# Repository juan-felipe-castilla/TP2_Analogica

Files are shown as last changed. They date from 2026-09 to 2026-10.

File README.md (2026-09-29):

# Laboratorio 2: Amplificador BJT Multietapa con Espejo de Corriente NMOS

Repositorio del **Laboratorio 2** para la asignatura de Electrónica. El objetivo de este proyecto es diseñar, simular, implementar en PCB y caracterizar experimentalmente un amplificador en cascada basado en transistores BJT.

---

## 👥 Integrantes (Grupo N°)
- **[Castilla Juan Felipe]** 
- **[Agustin Eduardo Dalmazzo]**
- **[Julian Lopez Bernal]** 

---

## 🎯 Especificaciones de Diseño

| Parámetro | Valor Requerido |
| :--- | :--- |
| **Ganancia de Tensión de Transf. ($G_T$)** | $> 75$ |
| **Impedancia de Entrada ($Z_{in}$)** | $> 350\text{ k}\Omega$ |
| **Impedancia de Salida ($Z_o$)** | $8\Omega \pm 5\%$ |

---

## 🛠️ Estructura del Repositorio

```text
.
├── docs/                   # Guías, hojas de datos (datasheets) e informe final
│   └── Informe_Laboratorio_2.pdf
├── design/                 # Cálculos teóricos, hojas de cálculo o notebooks
├── simulation/             # Archivos de simulación (SPICE / LTspice / Altium)
│   ├── bias_point/         # Análisis del punto de operación (OP)
│   ├── ac_analysis/        # Respuestas en frecuencia (AC)
│   └── transient/          # Análisis temporal, ruido y THD (TRAN / NOISE / FFT)
├── pcb/                    # Archivos de diseño de circuito impreso (KiCad / Altium)
│   ├── schematics/
│   ├── layout/
│   └── gerbers/
└── README.md

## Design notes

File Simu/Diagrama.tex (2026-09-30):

\documentclass[border=5mm]{standalone}
\usepackage[siunitx, american]{circuitikz}

\begin{document}
\begin{circuitikz}[scale=0.85, transform shape, line width=0.6pt]
    
    % ---------------------------------------------------
    % ETAPA 1: Entrada y Par Darlington (Q1, Q2)
    % ---------------------------------------------------
    % Fuente de entrada y NodoInput
    \draw (0,0) node[ground]{} 
          to[sV, l=$V_1$] (0,4)
          to[short, -*] (1.5,4) node[above]{NodoInput}
          to[short] (3,4) node[above]{B1};
          
    % Resistencia de base Q1
    \draw (3,4) to[R, l=$R_{BD}$] (3,0) node[ground]{};
    
    % Transistor Q1 (NPN)
    \draw (3,4) to[R, l=$h_{ie1}$, i=$i_{b1}$] (6,4) node[above right]{E1};
    \draw (6,7) node[ground, rotate=180]{} node[right]{C1} 
          to[cI, l=$\beta i_{b1}$] (6,4); 
    
    % Transistor Q2 (NPN)
    \draw (6,4) to[short] (8,4) node[above]{B2};
    \draw (8,4) to[R, l=$h_{ie2}$, i=$i_{b2}$] (11,4) node[above right]{E2};
    \draw (11,7) node[ground, rotate=180]{} node[right]{C2} 
          to[cI, l=$\beta i_{b2}$] (11,4); 
    
    % Resistencia de emisor Q2
    \draw (11,4) to[R, l=$R_{ED}$] (11,0) node[ground]{};

    % ---------------------------------------------------
    % ETAPA 2: Emisor Común (Q3)
    % ---------------------------------------------------
    % Resistencias de polarización separadas (R1E y R2E)
    \draw (11,4) to[short] (12.5,4);
    \draw (12.5,4) to[R, l=$R_{1E}$] (12.5,0) node[ground]{};
    \draw (12.5,4) to[short] (14,4);
    \draw (14,4) to[R, l=$R_{2E}$] (14,0) node[ground]{};
    
    % Transistor Q3 (NPN)
    \draw (14,4) to[short] (15.5,4) node[above]{B3};
    \draw (15.5,4) to[R, l=$h_{ie3}$, i=$i_{b3}$] (15.5,0) node[below right]{E3} node[ground]{};
    \draw (18,4) node[above]{C3} 
          to[cI, l=$\beta i_{b3}$] (18,0) node[below right]{E3} node[ground]{};
          
    % Resistencia de colector de Q3
    \draw (18,4) to[short] (19.5,4) 
          to[R, l=$R_{CE}$] (19.5,0) node[ground]{};

    % ---------------------------------------------------
    % ETAPA 3: Par Sziklai y Carga (Q4, Q5, Salida)
    % ---------------------------------------------------
    % Resistencias de polarización separadas (R1S y R2S)
    \draw (19.5,4) to[short] (21,4);
    \draw (21,4) to[R, l=$R_{1S}$] (21,0) node[ground]{};
    \draw (21,4) to[short] (22.5,4);
    \draw (22.5,4) to[R, l=$R_{2S}$] (22.5,0) node[ground]{};
    
    % Transistor Q4 (NPN)
    \draw (22.5,4) to[short] (24,4) node[above]{B4};
    \draw (24,4) to[R, l=$h_{ie4}$, i=$i_{b4}$] (27,4) node[below right]{E4};
    \draw (27,7) node[left]{C4} 
          to[cI, l=$\beta i_{b4}$] (27,4);
    
    % Transistor Q5 (PNP)
    \draw (27,7) node[above left]{B5} 
          to[R, l=$h_{ie5}$, i<=$i_{b5}$] (30,7) node[above right]{E5} node[ground, rotate=180]{};
    \draw (30,7) to[cI, l=$\beta i_{b5}$] (30,4) node[below]{C5};
    \draw (30,4) to[short] (27,4); 
    
    % NodoOut y resistencia de emisor Sziklai
    \draw (27,4) to[short, -*] (29,4) node[above]{NodoOut};
    \draw (29,4) to[R, l=$R_{ES}$] (29,0) node[ground]{};
    
    % Red de Carga final (RO y RL en serie)
    \draw (29,4) to[short] (31,4) 
          to[R, l=$R_O$] (31,2) 
          to[R, l=$R_L$] (31,0) node[ground]{};

\end{circuitikz}
\end{document}

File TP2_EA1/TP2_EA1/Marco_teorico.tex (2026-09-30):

\section{Marco Teórico}

\subsection{Amplificación en Circuitos con BJT}

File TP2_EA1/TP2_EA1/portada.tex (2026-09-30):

\begin{titlepage}

\thispagestyle{empty}

% Portada Custom, ver /maketitle: https://www.overleaf.com/learn/latex/How_to_Write_a_Thesis_in_LaTeX_(Part_5)%3A_Customising_Your_Title_Page_and_Abstract

\begin{tikzpicture}[remember picture,overlay]
    \node[opacity=0.2,anchor=center] at (current page.center) 
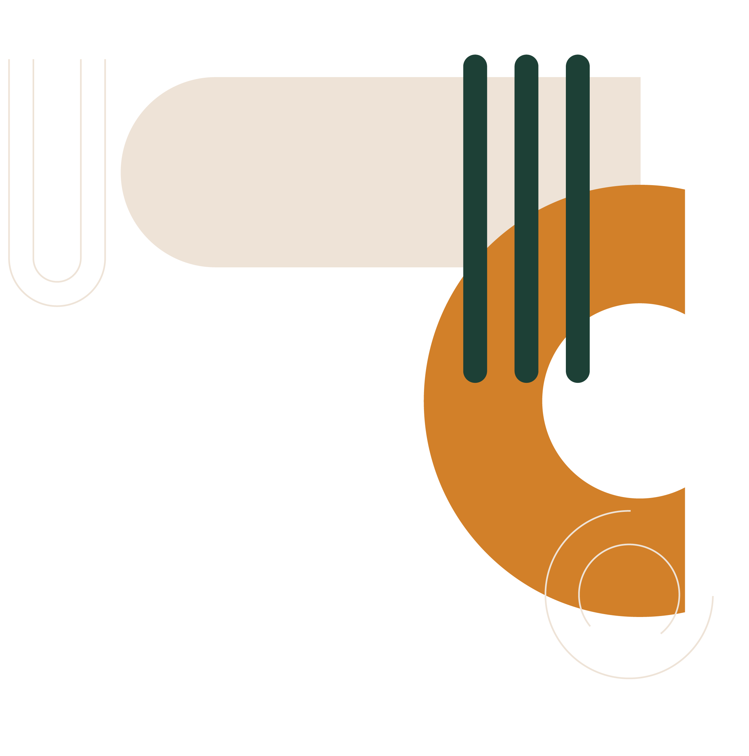
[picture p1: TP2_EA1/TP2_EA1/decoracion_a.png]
        {};
\end{tikzpicture}

\begin{center}
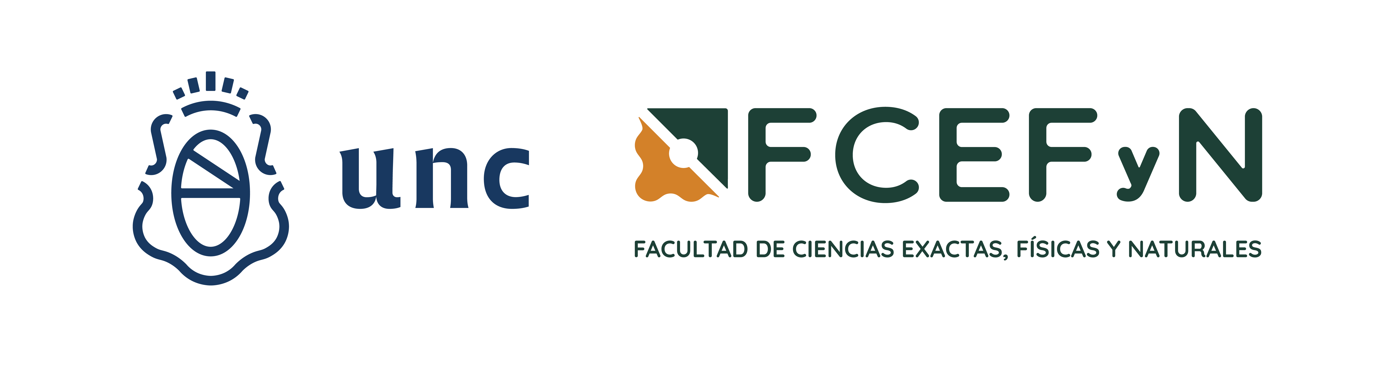
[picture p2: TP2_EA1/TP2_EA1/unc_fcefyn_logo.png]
    
    \\[0.5cm]
    \LARGE Universidad Nacional de Córdoba\\[0.5cm] 
    \large Facultad de Ciencias Exactas, Físicas y Naturales \\[0.5cm] 
    \large Materia
    \\[0.2cm]
    \large Trabajo Práctico N° 2
    \\[0.2cm]
    \vspace{60pt}
    \begin{table}[!h]
    \centering
    \begin{tabular}{ll}
    \multicolumn{1}{c}{Nombre} & \multicolumn{1}{c}{DNI} \\
    Castilla, Juan Felipe & 45.886.652 \\
    Dalmazzo, Agustín Eduardo & 46.541.615 \\
    López Bernal, Julián & 45.107.175
    \end{tabular}
    \end{table}
    \vspace{20pt}
    \begin{table}[!h]
    \centering
    \begin{tabular}{ll}
    \multicolumn{1}{c}{Docentes} & Prof. Dadam, Federico Tomás \\
     & Prof. Gallardo, Fernando José \\
     & Prof. Petrashin, Pablo Antonio \\
    \end{tabular}
    \end{table}
    \vfill
    Córdoba, República Argentina\\
    \today
\end{center}

\end{titlepage}

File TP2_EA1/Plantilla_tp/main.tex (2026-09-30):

\documentclass{article}
\usepackage[utf8]{inputenc}
\usepackage{graphicx}
\usepackage[spanish,es-tabla]{babel}
\usepackage{amsmath}
\usepackage[a4paper,margin=1in]{geometry}
\usepackage{subcaption}
\usepackage{amssymb}
\usepackage[hidelinks]{hyperref}
\usepackage{mathtools}
\usepackage[table,xcdraw]{xcolor}
\usepackage{biblatex}
\usepackage{enumitem}
\usepackage{csquotes}
\usepackage{circuitikz}
\usepackage{siunitx}

%Formateo etiquetas
\hypersetup{
    colorlinks=true,
    linkcolor=blue,    
    citecolor=blue,
    urlcolor=blue,
    filecolor=blue
}

\addbibresource{bibliografia.bib} %archivo de bibliografia

\begin{document}

%Configuro referencias automáticas
\renewcommand{\figureautorefname}{Fig.}
\renewcommand{\tableautorefname}{Tab.}
\renewcommand{\equationautorefname}{Ec.}

\input{titlepage}
\newpage
\vspace*{\fill}
\begin{center}
    (Página intencionalmente blanca) % Dejar para escribir los comentarios de corrección sobre esta página
\end{center}

\newpage

\tableofcontents
\newpage
\listoffigures
\newpage
\listoftables

\newpage

\input{seccion1}\label{section:one}
\newpage
\input{seccion2}
\newpage
\printbibliography
\end{document}

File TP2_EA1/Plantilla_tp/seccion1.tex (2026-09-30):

\section{Introducción}

Este documento contiene algunos elementos típicos usados en informes técnico o de laboratorio. Hay muchos recursos para aprender \LaTeX como:

\begin{itemize}
    \item \href{https://www.overleaf.com/learn}{Tutoriales de Overleaf}
    \item \href{https://latexguide.org/}{LaTeX Beginner's Guide}
    \item \href{https://tobi.oetiker.ch/lshort/lshort.pdf}{The Not So Short Introduction to \LaTeX}
    \item \href{https://www.latex-project.org/help/books/tlc3-digital-chapter-samples.pdf}{The \LaTeX Companion}
\end{itemize}

\subsection{Estilos de texto y listas}

Esto es un texto de ejemplo. Para generar párrafos en latex se puede escribir normalmente en un archivo \texttt{.tex}. Notar que en el editor un mismo párrafo aparece en una única línea de ``código".

Se puede modificar el estilo de texto para hacer \textit{partes en itálica} y \textbf{partes en negrita}, además se pueden incluir \texttt{palabras en fuente monoespaciada} o \underline{texto subrayado}. Además se pueden insertar listados:

\begin{itemize}
    \item Item principal
    \begin{itemize}
        \item Subitem 1
        \item Subitem 2
    \end{itemize}
    \item Otro item principal
\end{itemize}

Enumeraciones de items:

\begin{enumerate}
    \item Primer Item
    \begin{enumerate}
        \item Subitem enumerado
        \item Otro subitem enumerado
    \end{enumerate}
    \item Segundo item
\end{enumerate}

Con otro tipo de simbolos:

\begin{itemize}[label=$\Rightarrow$]
    \item Item 
    \item Otro item
        \begin{itemize}[label=$\blacktriangleright$]
            \item Un subitem
        \end{itemize}
\end{itemize}

También se pueden crear enumeraciones legales:

\begin{enumerate}[label=\arabic*.]
    \item Nivel 1, estilo legal, separado por puntos
    \begin{enumerate}[label=\theenumi\arabic*.]
        \item Nivel 2
        \begin{enumerate}[label=\theenumii\arabic*.]
            \item Nivel 3
        \end{enumerate}
    \end{enumerate}
    \item Regreso al Nivel 1
\end{enumerate}

O enumeraciones arbitrarias:

\begin{enumerate}[label=\arabic*.]
    \item Primer nivel (Número)
    \begin{enumerate}[label=\theenumi\alph*.]
        \item Segundo nivel (Letra separada por punto)
        \begin{enumerate}[label=\theenumii\roman*.]
            \item Tercer nivel (Romano separado por punto)
            \item Ejemplo de 1.a.ii.
        \end{enumerate}
    \end{enumerate}
    \item Regreso al nivel 1
    \begin{enumerate}[label=\theenumi\alph*.]
        \item Ejemplo de 2.a.
    \end{enumerate}
\end{enumerate}

\subsection{Ecuaciones}

Para insertar una ecuación se debe contar con el paquete \texttt{amsmath} incluido en el preámbulo del documento, en el archivo \texttt{main.tex} (o el archivo que se configure para compilarse como principal). Se puede insertar una ecuación en línea $e=mc^2$, o una ecuación enumerada o no enumerada. \footnote{Para más información de cómo escribir expresiones matemáticas con código visitar la url \url{https://www.overleaf.com/learn/latex/Mathematical_expressions}}

\begin{equation}
    s(\omega) = \left[ \left(\frac{1}{2}\right)^2 e^{j \pi \omega} \right] \int_{-\infty}^{\infty} \sum_{i=0}^{i=10} a_i dx
    \label{eq:algun_nombre}
\end{equation}

\begin{equation*}
    x_1,x_2 = \frac{-b \pm \sqrt{b^2 -4ac} }{2a}
\end{equation*}

Se pueden hacer matrices

\begin{equation}
    x = \begin{bmatrix}
        1 & 2 & 3\\
        a & b & c
        \end{bmatrix}
\end{equation}

Se pueden separar en renglones ecuaciones muy largas con \texttt{split}

\begin{equation}
    \begin{split}
        a = a_1 sin(\omega_0 t) + a_2 sin(2\omega_0 t) + a_3 sin(3\omega_0 t) + a_4 sin(4\omega_0 t) + a_5 sin(5\omega_0 t) + a_6 sin(6\omega_0 t) \\ + a_7 sin(7\omega_0 t) + a_8 sin(8\omega_0 t)
    \end{split}
\end{equation}

Se puede hacer un desarrollo de despejes agregando un caracter \texttt{\&} en el \textit{enviroment} \texttt{aligned} para alinear los miembros de ecuaciones

\begin{equation}
    \begin{split}
        V_{out} &= V_{in} \frac{R_1}{R_1+R_2} \\
        \frac{V_{in}}{V_{out}} &= \frac{R_1+R_2}{R_1} \\
        \frac{V_{in}}{V_{out}} &= 1+\frac{R_2}{R_1} \\
        \Aboxed{R_2 &= R_1 \left( \frac{V_{in}}{V_{out}} - 1 \right)}
    \end{split}
\end{equation}

Además, se pueden mostrar sistemas de ecuaciones, o ecuaciones con casos con \texttt{cases}:

\begin{equation}
    \begin{cases}
    x = 0 ~~ \forall ~~ x < 0\\
    x = 1 ~~ \forall ~~ 0 \leq x \geq 1 \\
    x = 0 ~~ \forall ~~ x > 1 
    \end{cases}
\end{equation}

Las ecuaciones se pueden referenciar si se le asigna una etiqueta con el comando \texttt{label}, por ejemplo, en la \autoref{eq:algun_nombre} se asigno una etiqueta llamada \textit{eq:algun\_nombre} y se usó para referenciarla, si se repiten las etiquetas, el editor lo indicará como un error.

También se puede escribir símbolos compuestos por múltiples letras, y unidades respetando el formato de IEEE. La \autoref{eq:non-comply-ieee} no cumple con este formato. La \autoref{eq:comply-ieee} lo hace, sin paquetes externos, y la \autoref{eq:comply-ieee-siunitx} lo hace, usando el paquete \textit{siunitx} (recomendado).

\begin{equation}
    SNR = 10~dB + 20\log\left(\frac{120~mW}{1~mW} \right)
    \label{eq:non-comply-ieee}
\end{equation}

\begin{equation}
    \mathrm{SNR} = 10~\text{dB} + 20 \log \left( \frac{120~\text{mW}}{1~\text{mW}} \right)
    \label{eq:comply-ieee}
\end{equation}

\begin{equation}
    \mathrm{SNR} = \qty{10}{dB} + 20 \log \left( \frac{\qty{120}{mW}}{\qty{1}{mW}} \right)
    \label{eq:comply-ieee-siunitx}
\end{equation}

\subsection{Figuras}

Para agregar figuras, asegurarse de contar con el paquete \texttt{graphicx} en el archivo a compilar. Notar que al igual que en las ecuaciones, se puede referenciar con la etiqueta, como el caso de la \autoref{fig:fm_radio_receiver}. Notar que el tamaño de la figura se especifica como un porcentaje del ancho del texto (delimitado por los márgenes). Al lado del inicio de la figura se puede especificar con una letra el lugar donde se quiere tratar de que \LaTeX ponga la figura, por ejemplo:

\begin{itemize}
    \item \texttt{h}: \textit{here} (\texttt{!h} más insistente)
    \item \texttt{t}: \textit{top}
    \item \texttt{b}: \textit{bottom}
    \item \texttt{ht}: Intenta \textit{here}, si no se puede, \textit{top}
    \item \textit{htbp}: here, top, bottom o flotante (p): Intenta ponerlo aquí, pero si no cabe, busca el mejor lugar
\end{itemize}

\begin{figure}[htbp]
    \centering
    %\includegraphics[width=0.8\textwidth]{figures/fm_radio_receiver.png}
    \caption{Circuito Recetor de FM}
    \label{fig:fm_radio_receiver}
\end{figure}

La \autoref{fig:tikzcirc} es un circuito diseñado con \url{https://circuit2tikz.tf.fau.de/designer/}, también se puede utilizar \url{https://tikzmaker.com/editor}

\begin{figure}[htbp]
    \centering
    %\resizebox{0.75\textwidth}{!}{\input{figures/ej_circuitikz.tikz}}
    \caption{Circuito de ejemplo con circuitkz}
    \label{fig:tikzcirc}
\end{figure}

\subsection{Tablas}

Se pueden generar tablas en \url{https://tablesgenerator.com/} (incluso se puede pegar desde Microsoft Excel, Libre Office Calc o Google Sheets y generar el código necesario). Al igual que con ecuaciones y figuras, se puede referenciar con la etiqueta: \autoref{tab:tabla_ejemplo}

\begin{table}[!h]
\centering
\begin{tabular}{|c|c|c|}
\hline
\rowcolor[HTML]{9698ED} 
\textbf{} & \textbf{Columna 1} & \textbf{Columna 2} \\ \hline
Fila 1 & $y = ax + b$ & 3 \\ \hline
Fila 2 & 5 & test \\ \hline
\end{tabular}
\caption{Tabla de Ejemplo}
\label{tab:tabla_ejemplo}
\end{table}

Si las tablas son demasiado grandes, se puede tildar la opción para que se ajusten al \texttt{textwidth} en \url{https://tablesgenerator.com/} 

\subsection{Quotation Marks}

En LaTeX, las comillas simples se generan usando ` (Ascii 92, acento grave) y ' (Ascii 39, comilla simple). Las comillas dobles se generan escribiendo `` (Dos veces acento grave) y '' (Dos veces comilla simple). El carácter " (Ascii 34, comilla doble no dirigida), produce comillas dobles de cierre: nunca debe usarse donde se requieren comillas de cierre).

\begin{center}

`Ejemplo de comillas simples bien utilizadas.' \\

``Ejemplo de doble comillas simple bien utilizada.'' \\

\spanishdeactivate{"}
"Ejemplo de comillas dobles mal utilizadas."

\end{center}

El último ejemplo ni siquiera funciona si se usa el package \textit{babel} configurado en español.

\subsection{Preambulo}

Algunas menciones importantes de las lineas del preámbulo (antes de \textit{begin{document}} en main.tex):

\begin{itemize}
    \item documentclass{article}: Establece el tipo de documento. Hay otras clases para libros, tesis, etc.
    \item usepackage[spanish,es-tabla]{babel}: al crear una imagen, tabla o ecuación, o al referenciarlas automáticamente se autocompletan con \textit{Figure}, \textit{Equation} y \textit{Table}. Para que estos textos (y otros) estén en español, se utiliza este paquete (y se configura para que diga \textit{Tabla} en lugar de \textit{Cuadro})
    \item [a4paper,margin=1in]{geometry}: Establece el tamaño de papel y de margenes.
\end{itemize}

\subsection{Citas}

Por último, se puede generar citas bibliográficas con bibtex, hay mucha documentación de cómo hacerlo en \href{https://www.overleaf.com/learn/latex/Bibliography_management_with_bibtex}{en este link}, pero se presenta un ejemplo sencillo. En cualquier artículo del IEEE se presenta una sección para copiar la información para poner en el archivo bib, este ejemplo se realizará con el artículo de \href{https://ieeexplore.ieee.org/document/8310054}{este enlace}. \cite{8310054}

También se puede crear una entrada de bibliografía con los datos que se dispongan y citarla. \cite{ea3_2023}

Además, se pueden referenciar secciones de este mismo trabajo (creando hipervínculos en el pdf): como este que refiere a la \autoref{section:two} o este otro que refiere a la \autoref{subsection:lorem-ipsum}

\subsection{Tips}

\begin{itemize}
    \item Overleaf es particularmente útil porque se puede trabajar de manera colaborativa (como en Google Docs), se puede hacer comentarios (como el que está hecho aquí), y se ven en el editor. Hay mucha documentación en \url{https://www.overleaf.com/learn}
    \begin{itemize}
        \item Se pueden ver los comentarios en el botón \textbf{Review Panel} de la izquierda del editor
        \item El documento se puede compartir con el botón \textbf{Share}
        \item Para implementar un control de cambios se puede sincronizar el proyecto con GitHub en el menú de integraciones.
        \item En la versión gratuita de Overleaf hay un límite de personas que pueden tener el documento compartido (hasta 3) y no se puede hacer un `control de cambios' en vivo. La versión gratuita también tiene un tiempo máximo de compilación, si tienen muchas imagenes muy `pesadas' es probable que necesiten usar un editor de \LaTeX offline
        \item Existe un chat entre los que estén conectados al documento. 
        \item Si el documento es pequeño se puede activar la auto-compilación para ver los cambios en el PDF en vivo (útil para empezar, pero a medida que se acostumbran es mejor compilar manualmente luego de muchos cambios). También existe la versión de compilación borrador (\textit{draft}), que no compila imágenes.
        \item Para insertar imágenes, se puede pegar directamente (Ctrl+V), abriendo un cuadro de dialogo para definir nombre, ubicación y ancho de la imagen, generando el código automáticamente.
        \item En Layout pueden modificar las ventanas para ver solo el código, o poner el PDF en otra pestaña
        \item En Menú (Esquina superior izquierda) pueden modificar el estilo del editor, el tema (poner modo oscuro), la fuente del editor, cambiar el idioma del corrector, el compilador, el archivo principal, etc. Además, pueden descargar el código fuente con todas las imagenes, o el PDF renderizado.
    \end{itemize}
    \item Overleaf tiene muy bajo tiempo de compilación permitido, para proyectos muy grandes que lo superan se puede evitar usar las opciones pagas de dos maneras:
    \begin{itemize}
        \item Activar el modo draft para trabajar colaborativamente y corroborar que funciona el código
        \item Si el modo draft no es suficiente, se pueden comentar bloques de código con los comandos \textit{begin{comment}} y \textit{end{comment}}
    \end{itemize}
    \item Hay muchas aplicaciones para editar \LaTeX offline, luego de usar las opciones anteriores se puede descargar alguna de estas alternativas 
    \begin{itemize}
        \item TeXStudio (\url{https://www.texstudio.org/}) + Miktex (\url{https://miktex.org/download}). TexStudio tiene un gestor de paquetes para descargar e instalar todos los paquetes que incluyen en el preámbulo.
        \item Se puede compilar directo en Visual Studio Code, utilizando la extensión LaTeX Workshop (\url{https://marketplace.visualstudio.com/items?itemName=James-Yu.latex-workshop}, es necesario también instalar Strawberry Perl para compilar \texttt{latexmk}, un script que automatiza la generación de los PDFs (\url{https://strawberryperl.com/}) y Miktex para instalar paquetes.
    \end{itemize}

    \item Hay muchos tutoriales disponibles, un aspecto importante de usar \LaTeX es utilizar la document class adecuada y saber buscar (preferentemente en inglés) lo que se necesita \url{https://www.overleaf.com/learn/latex/Learn_LaTeX_in_30_minutes}
    \item Existe un libro (no tan corto) de introducción a \LaTeX, para tener de referencia algunas funciones: \url{https://tobi.oetiker.ch/lshort/lshort.pdf}
    \item La documentación de la mayoría de los paquetes se puede encontrar en CTAN: \url{https://www.ctan.org/}
    \item Para escribir una tesis o proyecto integrador, puede ser interesante hacer un documento doble faz: \url{https://www.overleaf.com/learn/latex/Single_sided_and_double_sided_documents}
    \item Se puede modificar el tamaño de página y los márgenes \url{https://www.overleaf.com/learn/latex/Page_size_and_margins}
    \item Se pueden insertar PDFs enteros o partes de PDF directamente en el documento: \url{https://latex-tutorial.com/insert-pdf-file/}
    \item Se puede cambiar el estilo de listas de enumeración (1, 1.a, 1.b; 1, 1.1, 1.2; I, I.I, I.II): \url{https://www.overleaf.com/learn/latex/Lists}
    \item Se pueden personalizar los encabezados y pie de página: \url{https://es.overleaf.com/learn/latex/Headers_and_footers}
    \item Se puede reutilizar código de un informe para hacer presentaciones con beamer: \url{https://es.overleaf.com/learn/latex/Beamer}
    \item Se puede incluir imagenes en formato PDF para evitar que se pixelen: \url{https://www.ctan.org/pkg/pdfpages}
    \item Se puede cambiar la separación de párrafos, lineas, tamaños de fuentes y familias de fuentes.
    \item Existen paquetes para dibujar circuitos con código, no es recomendable si se usa Overleaf y hay una gran cantidad de circuitos en el documento, por el tiempo de compilación: Las documentación de este paquete es muy extensa: \url{https://es.overleaf.com/learn/latex/CircuiTikz_package} y \url{https://ctan.dcc.uchile.cl/graphics/pgf/contrib/circuitikz/doc/circuitikzmanual.pdf}
    \item En lugar de usar circuitikz, desde el 2023 existe una interfaz gráfica que genera el código.
    \item Usar la bibliografía con bibtex tiene la enorme ventaja de que fácilmente puede cambiarse el formato de las citas y las referencias, para adecuarse con los formatos solicitados por la facultad, congresos, revistas, etc. Se puede alterar el orden de las referencias, dividirlas según su tipo, y citar cosas con DOI (Digital object identifier) como artículos y libros, sitios web o cualquier tipo de material académico. Consultar la documentación: \url{https://www.overleaf.com/learn/latex/Bibliography_management_with_bibtex}
\end{itemize}

\subsection{Comentarios finales}

\begin{itemize}
    \item Este documento está dirigido a fomentar el uso de \LaTeX para la generación de informes académicos.
    \item En este link se encontrará la versión más nueva de este template: \url{https://www.overleaf.com/read/ssfxdztpsbsx#13d015}
    \item Existe otro template para hacer presentaciones: \url{https://www.overleaf.com/read/qcbhtvtbythb#c59265}
    \item Dirigir comentarios y sugerencias a \href{mailto:federico.tomas.dadam+template@unc.edu.com.ar}{federico.tomas.dadam@unc.edu.com.ar}
\end{itemize}

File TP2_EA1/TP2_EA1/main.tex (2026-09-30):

\documentclass{article}
\usepackage[utf8]{inputenc}
\usepackage{graphicx}
\usepackage[spanish,es-tabla]{babel}
\usepackage{amsmath}
\usepackage[a4paper,margin=1in]{geometry}
\usepackage{subcaption}
\usepackage{amssymb}
\usepackage[hidelinks]{hyperref}
\usepackage{mathtools}
\usepackage[table,xcdraw]{xcolor}
\usepackage{biblatex}
\usepackage{enumitem}
\usepackage{csquotes}
\usepackage{circuitikz}
\usepackage{siunitx}
\usepackage{newtxtext} % Carga la tipografía Times New Roman para todo el documento
\usepackage{titlesec}  % Permite formatear los títulos
\usepackage{hyperref}

% Definición de tamaños exactos con tipografía Times (tamaño, interlineado recomendado)
\newcommand{\sizedieciocho}{\fontsize{18}{22}\selectfont}
\newcommand{\sizedieciseis}{\fontsize{16}{20}\selectfont}
\newcommand{\sizecatorce}{\fontsize{14}{18}\selectfont}
\newcommand{\sizedoce}{\fontsize{12}{16}\selectfont}

% 1. Secciones (\section) - Tamaño 18
\titleformat{\section}
  {\normalfont\sizedieciocho\bfseries} % Times New Roman, 18pt, Negrita
  {}
  {0pt}
  {}

% 2. Subsecciones (\subsection) - Tamaño 16
\titleformat{\subsection}
  {\normalfont\sizedieciseis\bfseries} % Times New Roman, 16pt, Negrita
  {}
  {0pt}
  {}

% 3. Sub-subsecciones (\subsubsection) - Tamaño 14
\titleformat{\subsubsection}
  {\normalfont\sizecatorce\bfseries} % Times New Roman, 14pt, Negrita
  {}
  {0pt}
  {}

  % --- CONFIGURACIÓN DE INDENTACIÓN Y ESPACIOS ---
% Sintaxis: \titlespacing*{<comando>}{<indentación izquierda>}{<espacio antes>}{<espacio después>}

% Secciones: Sin indentación izquierda (0pt)
\titlespacing*{\section}{0pt}{14pt}{8pt}

% Subsecciones: Indentadas 0.5 centímetros hacia la derecha
\titlespacing*{\subsection}{0.5cm}{12pt}{6pt}

% Sub-subsecciones: Indentadas 1.0 centímetro hacia la derecha
\titlespacing*{\subsubsection}{1.0cm}{10pt}{4pt}

%Formateo etiquetas
\hypersetup{
    colorlinks=true,
    linkcolor=blue,    
    citecolor=blue,
    urlcolor=blue,
    filecolor=blue
}

\addbibresource{bibliografia.bib} %archivo de bibliografia

%Configuro referencias automáticas
\renewcommand{\figureautorefname}{Fig.}
\renewcommand{\tableautorefname}{Tab.}
\renewcommand{\equationautorefname}{Ec.}

\setcounter{secnumdepth}{0} % Quita los números de los títulos
\setcounter{tocdepth}{3}    % Obliga al índice a mostrar los títulos hasta sub-subsecciones

\begin{document}
\input{TP2_EA1/portada}
\newpage
\vspace*{\fill} %Pongo una pagina en blanco llena
\newpage
\tableofcontents
\newpage
\listoffigures
\newpage
\listoftables
\newpage
\input{TP2_EA1/Intro}
\newpage
\input{TP2_EA1/Marco_teorico}
\newpage
\input{TP2_EA1/Desarrollo}
\newpage
\input{TP2_EA1/Conclusion}
\newpage
\printbibliography
\end{document}

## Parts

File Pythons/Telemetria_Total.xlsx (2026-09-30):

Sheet: Transistores (V & Potencia)
Transistor | Tipo | Vc [V] | Vb [V] | Ve [V] | Vceq [V] | Potencia [mW] | Región DC
Q1 | NPN | 12 | 10.1264 | 9.5089 | 2.4911 | 2.19 | Activa
Q2 | NPN | 12 | 9.5089 | 8.6819 | 3.3181 | 610.73 | Activa
Q3 | NPN | 3.4243 | 2.144 | 1.5166 | 1.9077 | 2.408 | Activa
Q4 | NPN | 11.1623 | 7.7351 | 7.0647 | 4.0976 | 25.608 | Activa
Q5 | PNP | 7.0647 | 11.1623 | 12 | 4.9353 | 3460.977 | Activa

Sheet: Resistencias (Potencia)
Resistencia | Valor [Ω] | Caída Vdc [V] | Corriente [mA] | Potencia [mW]
RBD | 1000000 | 1.8736 | 0.0019 | 0.004
RED | 47 | 8.6819 | 184.7213 | 1603.733
R1E | 120000 | 9.856 | 0.0821 | 0.81
R2E | 27000 | 2.144 | 0.0794 | 0.17
RCE | 6800 | 8.5757 | 1.2611 | 10.815
REE | 1200 | 1.5166 | 1.2639 | 1.917
R2S | 100000 | 7.7351 | 0.0774 | 0.598
R1S | 47000 | 4.2649 | 0.0907 | 0.387
RES | 10 | 7.0647 | 706.4694 | 4990.99
RO | 7.5 | 0 | 0 | 0
RL | 8 | 0 | 0 | 0

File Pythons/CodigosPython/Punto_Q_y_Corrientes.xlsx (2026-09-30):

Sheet: Corrientes Resistencias
Resistencia | Valor [Ω] | Nodo + | Nodo - | Caída Vdc [V] | Corriente [mA] | Potencia [mW]
RBD | 1000000 | N001 | N007 | 1.8736 | 0.0019 | 0.004
RED | 47 | N005 | 0 | 8.6819 | 184.7213 | 1603.733
R1E | 120000 | N001 | N006 | 9.856 | 0.0821 | 0.81
R2E | 27000 | N006 | 0 | 2.144 | 0.0794 | 0.17
RCE | 6800 | N001 | N003 | 8.5757 | 1.2611 | 10.815
REE | 1200 | N011 | 0 | 1.5166 | 1.2639 | 1.917
R2S | 100000 | N004 | 0 | 7.7351 | 0.0774 | 0.598
R1S | 47000 | N001 | N004 | 4.2649 | 0.0907 | 0.387
RES | 10 | N008 | 0 | 7.0647 | 706.4694 | 4990.99
RO | 7.5 | NODOOUT | N008 | 0 | 0 | 0
RL | 8 | N009 | 0 | 0 | 0 | 0

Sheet: Puntos Q Transistores
Transistor | Tipo | Vc [V] | Vb [V] | Ve [V] | Vceq [V] | Vbeq [V] | Región DC
Q1 | NPN | 12 | 10.1264 | 9.5089 | 2.4911 | 0.6175 | Activa
Q2 | NPN | 12 | 9.5089 | 8.6819 | 3.3181 | 0.827 | Activa
Q3 | NPN | 3.4243 | 2.144 | 1.5166 | 1.9077 | 0.6274 | Activa
Q4 | NPN | 11.1623 | 7.7351 | 7.0647 | 4.0976 | 0.6704 | Activa
Q5 | PNP | 7.0647 | 11.1623 | 12 | 4.9353 | -0.8377 | Activa

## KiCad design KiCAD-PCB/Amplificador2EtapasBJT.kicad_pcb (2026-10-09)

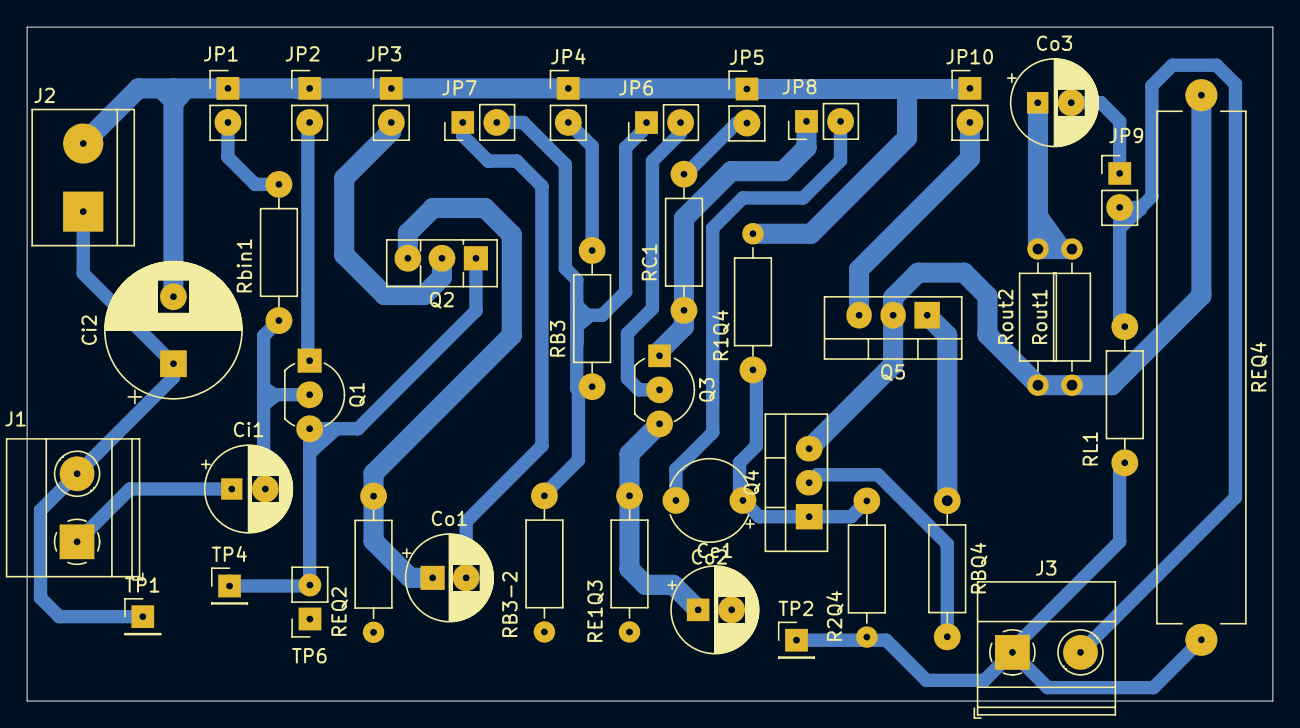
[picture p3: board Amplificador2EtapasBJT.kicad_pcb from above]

Board: 2 copper layers, 93.0 x 50.3 mm, 41 parts (0 on the bottom side), 25 nets.

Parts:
Ce1: 33uF; CP_Radial_D6.3mm_P2.50mm
Ci1: 10uF; CP_Radial_D6.3mm_P2.50mm
Ci2: 10uF; CP_Radial_D10.0mm_P5.00mm
Co1: 10uF; CP_Radial_D6.3mm_P2.50mm
Co2: 10uF; CP_Radial_Tantal_D6.0mm_P5.00mm
Co3: 1000uF; CP_Radial_D6.3mm_P2.50mm
J1: Vin; TerminalBlock_Phoenix_MKDS-1,5-2-5.08_1x02_P5.08mm_Horizont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
J2: CC; TerminalBlock_bornier-2_P5.08mm
J3: Vout; TerminalBlock_Phoenix_MKDS-1,5-2-5.08_1x02_P5.08mm_Horizont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
JP1: RbQ1; PinHeader_1x02_P2.54mm_Vertical
JP2: C-Q1; PinHeader_1x02_P2.54mm_Vertical
JP3: C-Q2; PinHeader_1x02_P2.54mm_Vertical
JP4: Div-Q3; PinHeader_1x02_P2.54mm_Vertical
JP5: C-Q3; PinHeader_1x02_P2.54mm_Vertical
JP6: B-Q3; PinHeader_1x02_P2.54mm_Vertical
JP7: FinEtapa1; PinHeader_1x02_P2.54mm_Vertical
JP8: FinEtapa2; PinHeader_1x02_P2.54mm_Vertical
JP9: ConRL; PinHeader_1x02_P2.54mm_Vertical
JP10: C-Q5; PinHeader_1x02_P2.54mm_Vertical
Q1: BC546 B NPN; TO-92_Inline_Wide
Q2: BD 139NPN; TO-126-3_Vertical
Q3: NPN; TO-92_Inline_Wide
Q4: NPN; TO-220-3_Vertical
Q5: PNP; TO-220-3_Vertical
R1Q4: 47k; R_Axial_DIN0207_L6.3mm_D2.5mm_P10.16mm_Horizontal
R2Q4: 100k; R_Axial_DIN0207_L6.3mm_D2.5mm_P10.16mm_Horizontal
RB3: 120k; R_Axial_DIN0207_L6.3mm_D2.5mm_P10.16mm_Horizontal
RB3-2: 27k; R_Axial_DIN0207_L6.3mm_D2.5mm_P10.16mm_Horizontal
RBQ4: 100; R_Axial_DIN0207_L6.3mm_D2.5mm_P10.16mm_Horizontal
RC1: 6.8k; R_Axial_DIN0207_L6.3mm_D2.5mm_P10.16mm_Horizontal
RE1Q3: 1.2k; R_Axial_DIN0207_L6.3mm_D2.5mm_P10.16mm_Horizontal
REQ2: 47; R_Axial_DIN0207_L6.3mm_D2.5mm_P10.16mm_Horizontal
REQ4: 10; R_Axial_Power_L38.0mm_W6.4mm_P40.64mm
RL1: 8; R_Axial_DIN0207_L6.3mm_D2.5mm_P10.16mm_Horizontal
Rbin1: 1M; R_Axial_DIN0207_L6.3mm_D2.5mm_P10.16mm_Horizontal
Rout1, Rout2: 15; R_Axial_DIN0207_L6.3mm_D2.5mm_P10.16mm_Horizontal
TP1, TP2: TPFrec; PinHeader_1x01_P2.54mm_Vertical
TP4: TPB-Q2; PinHeader_1x01_P2.54mm_Vertical
TP6: TPB2E1; PinSocket_1x02_P2.54mm_Vertical

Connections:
Earth: Ce1.2, Ci2.1, J1.2, J2.1, J3.1, R2Q4.1, RB3-2.2, RE1Q3.2, REQ2.2, REQ4.2, RL1.2, TP1.1, TP2.1, TP6.1
unnamed: Co3.1, Rout1.2, Rout2.2
unnamed: Ci1.1, J1.1
unnamed: Ci2.2, J2.2, JP1.1 (A), JP2.1 (A), JP3.1 (A), JP4.1 (A), JP5.1 (A), JP10.1 (A), R1Q4.2
unnamed: J3.2, JP9.2 (B), RL1.1
unnamed: JP1.2 (B), Rbin1.1
unnamed: JP2.2 (B), Q1.1 (C)
unnamed: JP3.2 (B), Q2.1 (C)
unnamed: JP4.2 (B), RB3.1
unnamed: JP5.2 (B), RC1.1
unnamed: JP6.1 (A), JP7.2 (B), RB3.2, RB3-2.1
unnamed: JP6.2 (B), Q3.2 (B)
unnamed: Co1.2, JP7.1 (A)
unnamed: JP8.1 (A), Q3.1 (C), RC1.2
unnamed: Co2.2, JP8.2 (B)
unnamed: Co3.2, JP9.1 (A)
unnamed: JP10.2 (B), Q5.3 (E)
unnamed: Ci1.2, Q1.2 (B), Rbin1.2
unnamed: Q1.3 (E), Q2.2 (B), TP4.1, TP6.2
unnamed: Co1.1, Q2.3 (E), REQ2.1
unnamed: Ce1.1, Q3.3 (E), RE1Q3.1
unnamed: Co2.1, Q4.1 (C), R1Q4.1, R2Q4.2
unnamed: Q4.2 (B), RBQ4.2
unnamed: Q4.3 (E), Q5.2 (B), REQ4.1, Rout1.1, Rout2.1
unnamed: Q5.1 (C), RBQ4.1

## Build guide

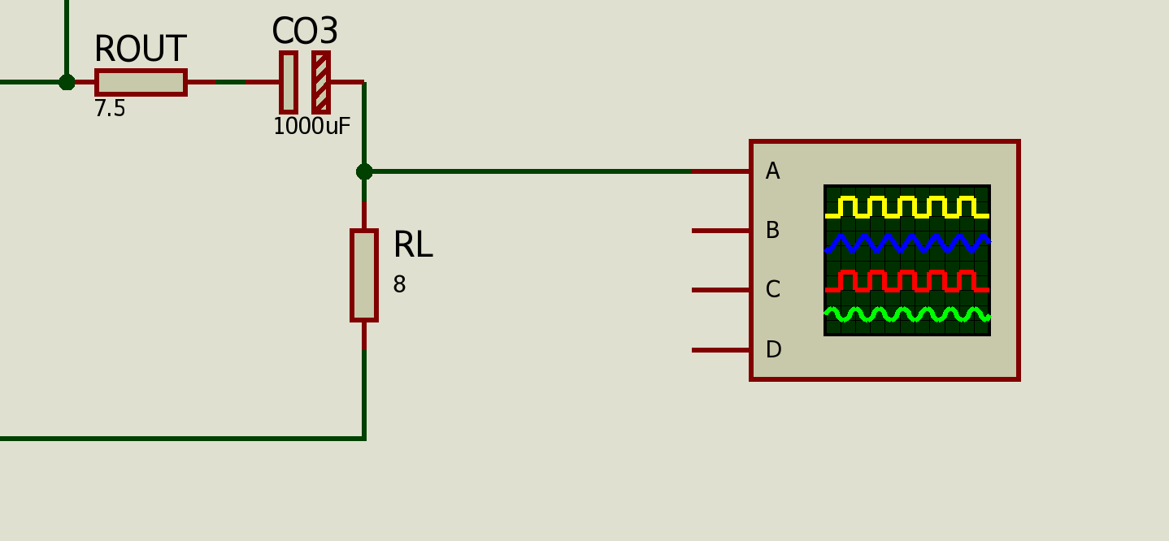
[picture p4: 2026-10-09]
SetupMediciones/TensionesCorrientes/MaxTension.png

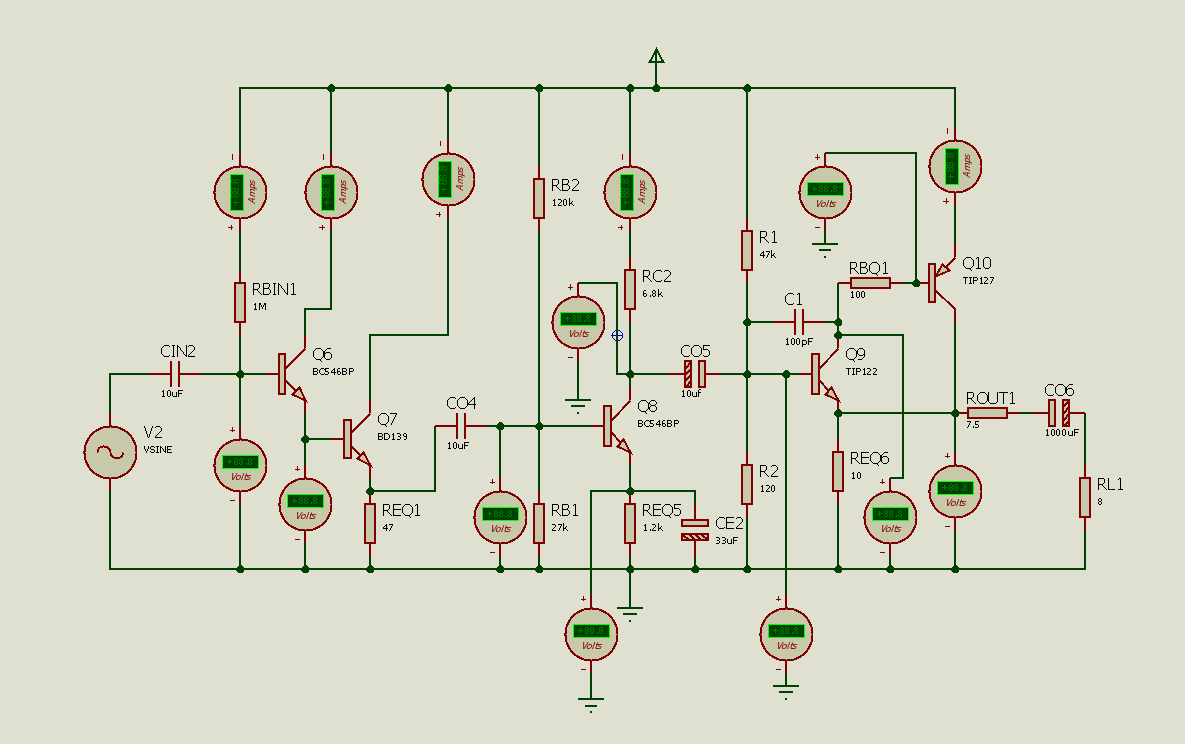
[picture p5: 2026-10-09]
SetupMediciones/TensionesCorrientes/VITransistores.png

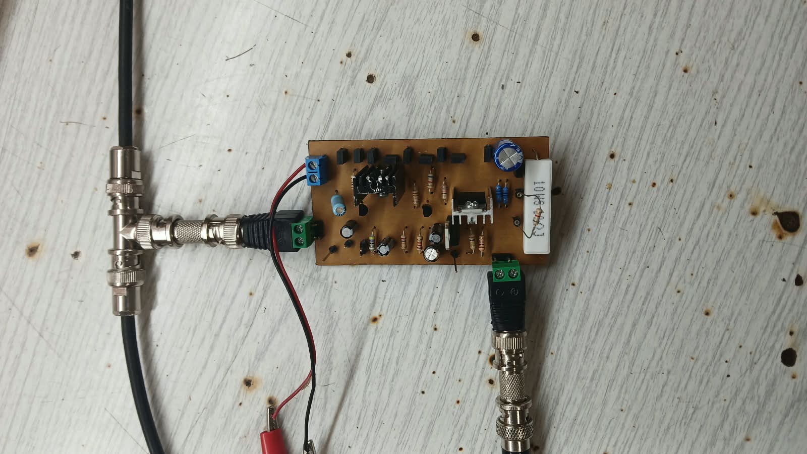
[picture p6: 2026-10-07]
FotosMed/Setup/PlacaConectada.jpeg

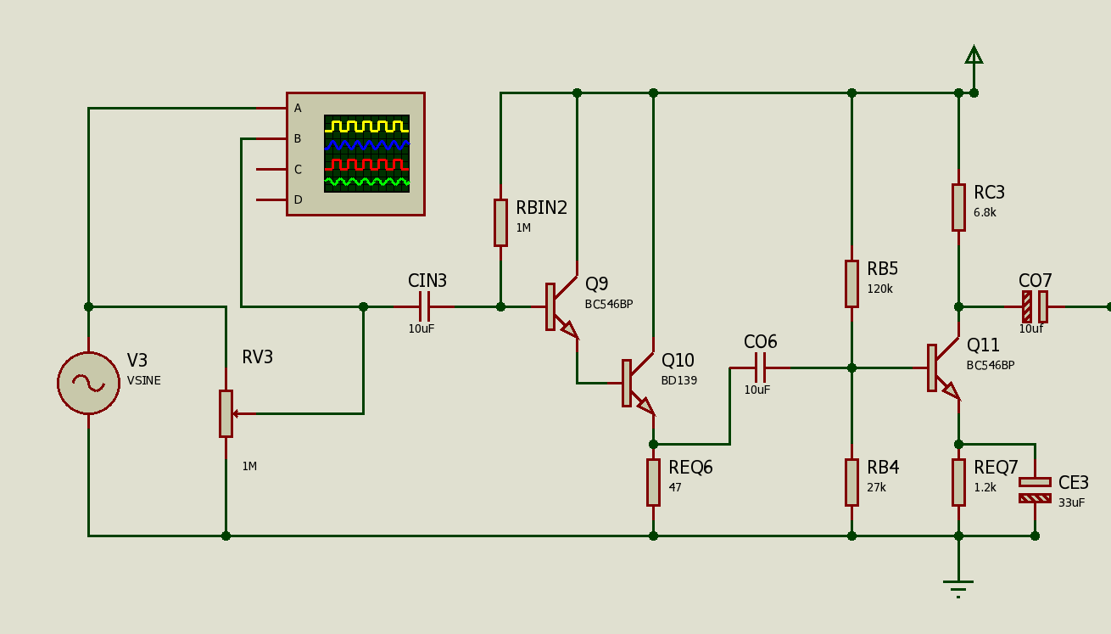
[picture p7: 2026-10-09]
SetupMediciones/ZIN/Zin12.png

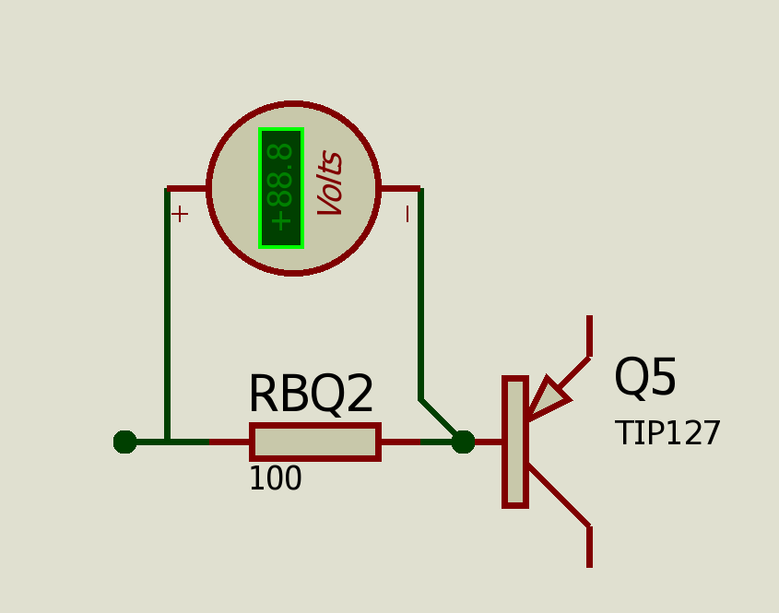
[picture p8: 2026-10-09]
SetupMediciones/TensionesCorrientes/IcQ4.png

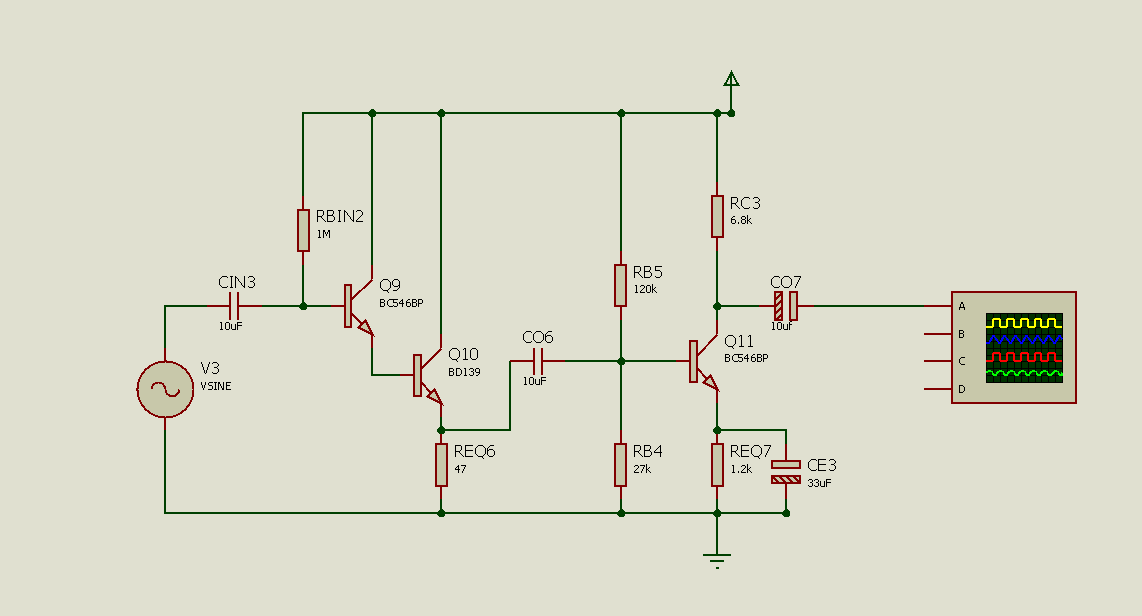
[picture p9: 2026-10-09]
SetupMediciones/ZOUT/Zout12VACIO.png

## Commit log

2026-09-29 Creación de carpetas
2026-09-29 Update project description in README
    Removed mention of NMOS current mirror and source degeneration.
2026-09-30 Agregado de los codigos de pyhton y el kiCAD, HAY QUE ORDENARLO
    [Amplificador2EtapasBJT.kicad_pcb, Amplificador2EtapasBJT.kicad_sch, Punto_Q_y_Corrientes.xlsx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]
2026-09-30 Correccion de Esquematico y PCB
    [Amplificador2EtapasBJT.kicad_pcb, Amplificador2EtapasBJT.kicad_sch]
2026-09-30 agregado xlms
    [Telemetria_Total.xlsx]
2026-10-03 Octaves Globales de todo el ampli
2026-10-04 Ganancias e impedancias de cada etapa
2026-10-04 Corrección de cálculo de hie
2026-10-04 Ajustes de las Rectas de Carga
2026-10-04 Actualización del Informe
    Pongo el Zip porque Overleaf es re gato si lo descargan tienen los archivos con mi úiltima actualización y no les subo los 555 archivos distintos
2026-10-04 Actualizacion del Sch y PCB a corregir
    [Amplificador2EtapasBJT.kicad_pcb, Amplificador2EtapasBJT.kicad_sch]
2026-10-05 Correcciones del Octave y avance con el informe
2026-10-06 fotos de med
2026-10-07 primera tanda de fotos
2026-10-08 Ajustes en octave, carga de imágenes, limpio la basura del informe
2026-10-08 Imagenes del Setup de Proteus
    [Amplificador2EtapasBJT.kicad_pcb, Amplificador2EtapasBJT.kicad_sch]
2026-10-09 pusheo un monotn de cosas
    [Amplificador2EtapasBJT.kicad_pcb, Amplificador2EtapasBJT.kicad_sch]
2026-10-10 Update title in README.md for clarity
    Removed 'con Espejo de Corriente NMOS' from the title.
2026-10-13 ajustes octave y final de informe
